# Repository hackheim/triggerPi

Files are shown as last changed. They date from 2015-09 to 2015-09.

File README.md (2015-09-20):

# triggerPi
DSLR Remote trigger kippah  for Raspberry Pi

<br />This work is licensed under a <a rel="license" href="http://creativecommons.org/licenses/by-sa/4.0/">Creative Commons Attribution-ShareAlike 4.0 International License</a>.

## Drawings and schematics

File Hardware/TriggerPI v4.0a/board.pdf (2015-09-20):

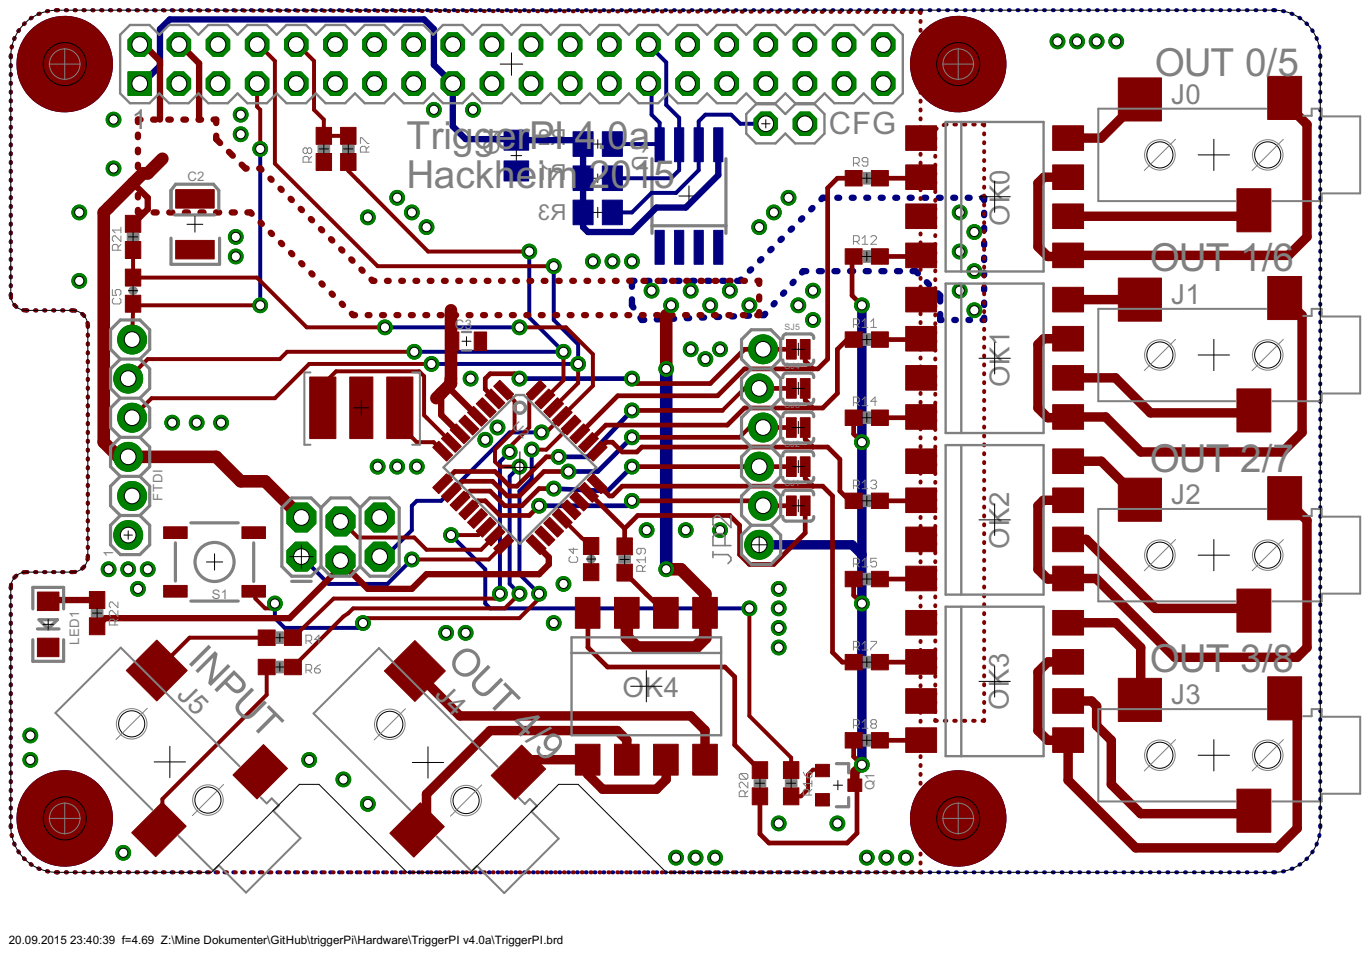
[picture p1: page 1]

20.09.2015 23:40:39 f=4.69 Z:\Mine Dokumenter\GitHub\triggerPi\Hardware\TriggerPI v4.0a\TriggerPI.brd

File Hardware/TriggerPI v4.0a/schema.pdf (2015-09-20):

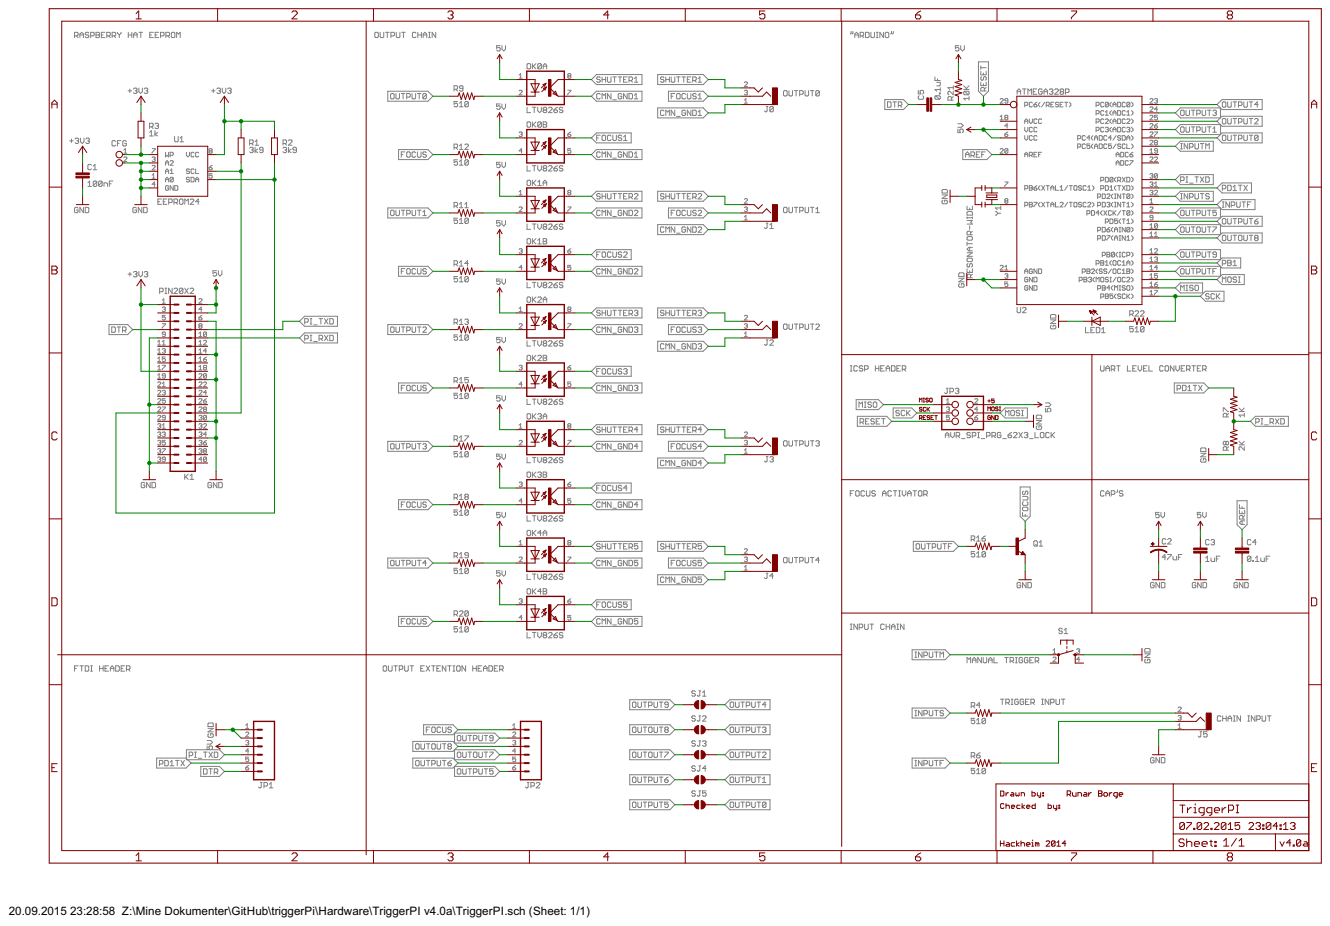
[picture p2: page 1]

20.09.2015 23:28:58 Z:\Mine Dokumenter\GitHub\triggerPi\Hardware\TriggerPI v4.0a\TriggerPI.sch (Sheet: 1/1)

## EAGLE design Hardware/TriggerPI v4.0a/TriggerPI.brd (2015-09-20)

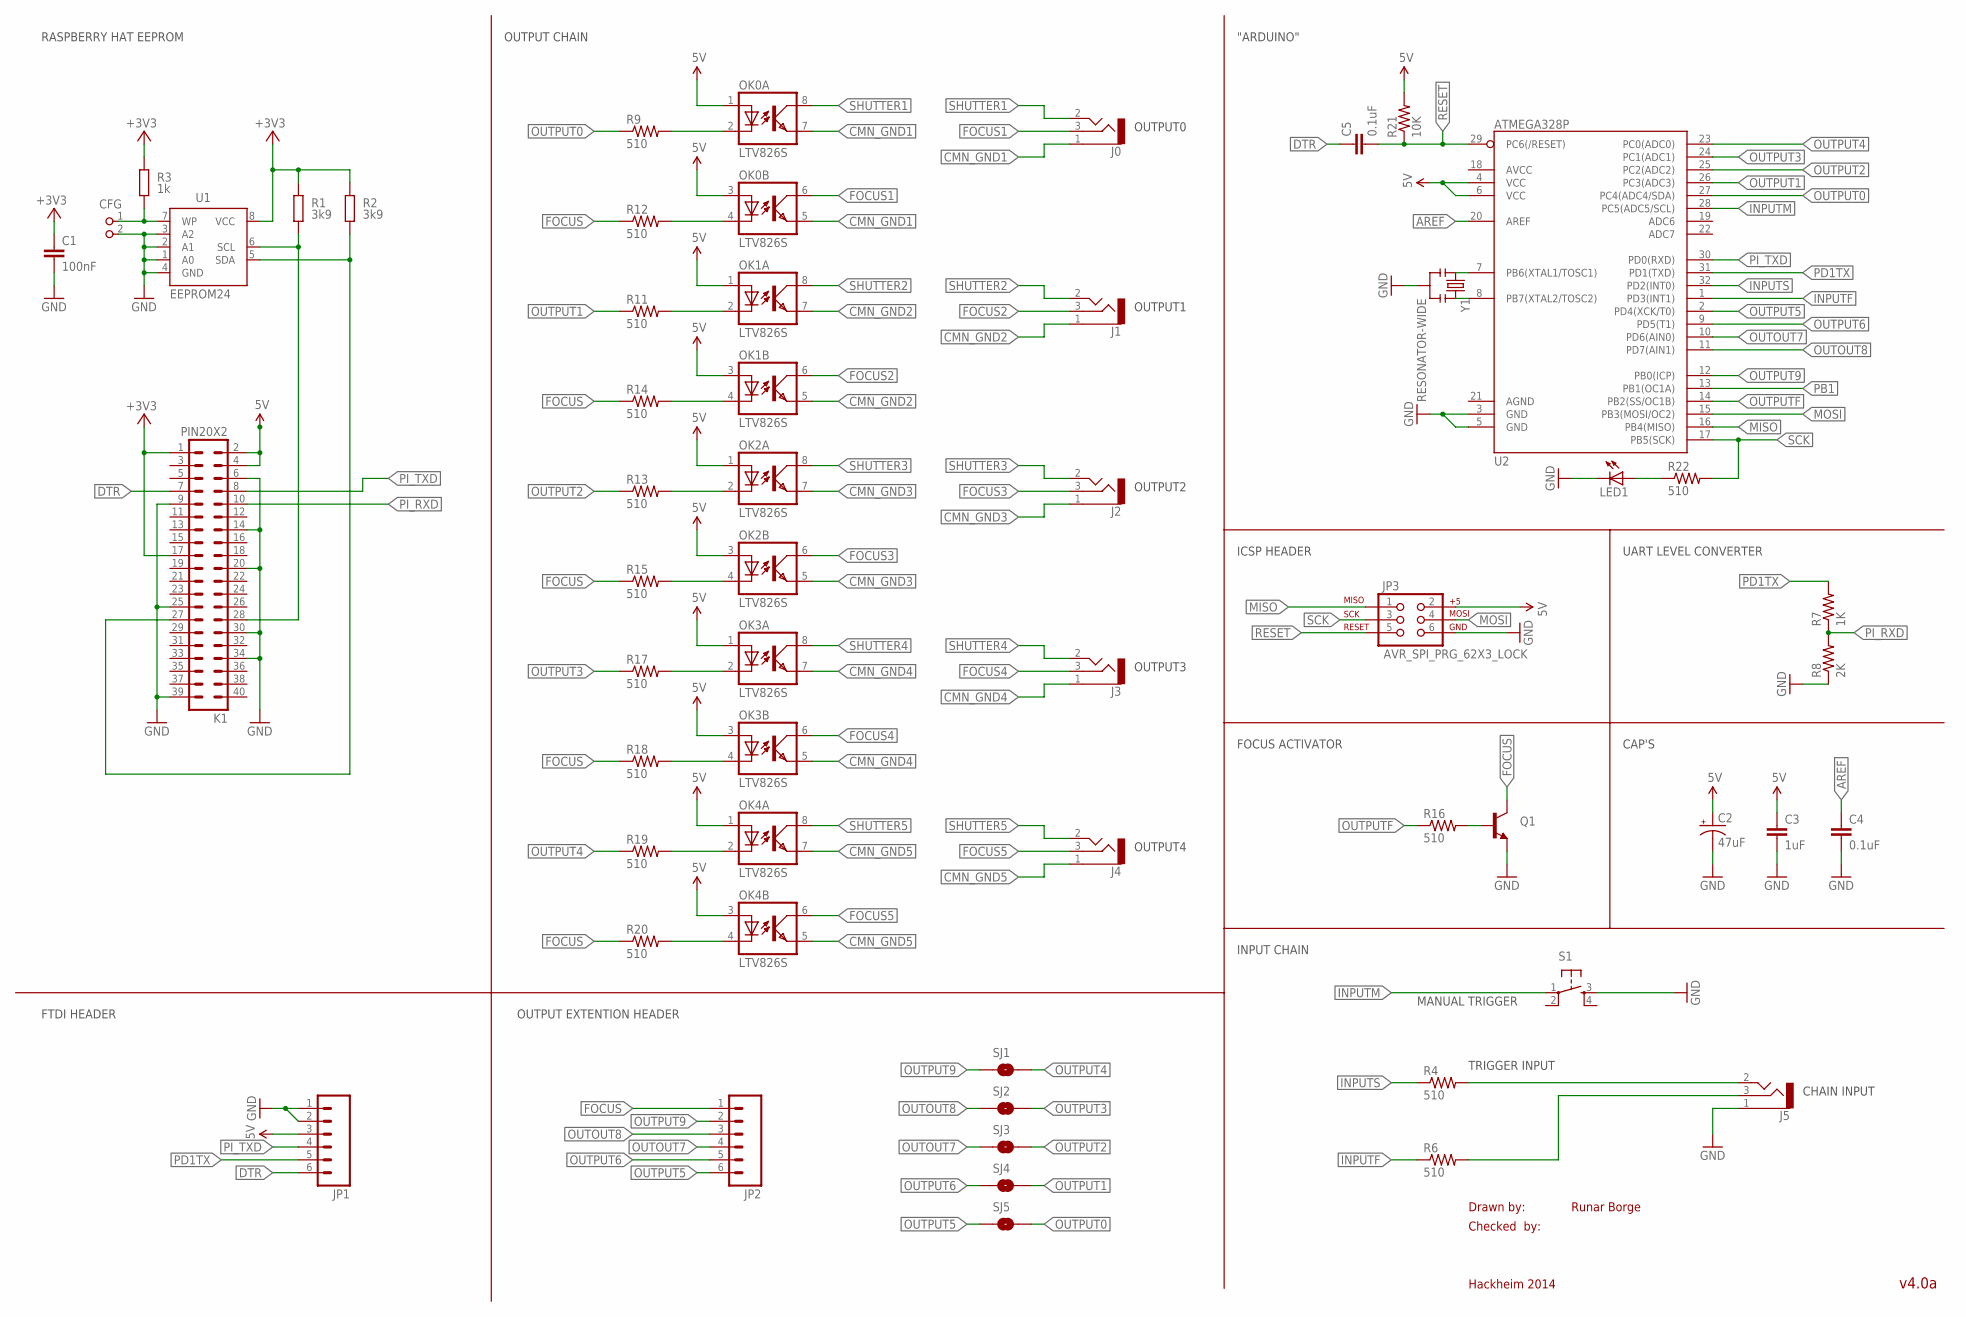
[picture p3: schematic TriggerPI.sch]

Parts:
C1: 100nF; C0805K
C2: 47uF; EIA3528; DIGIKEY 478-3132-1-ND
C3: 1uF; 0805; DIGIKEY 445-7547-1-ND
C4, C5: 0.1uF; 0603-CAP; DIGIKEY 445-1314-1-ND
CFG: PIN2_100; PIN_W_2
J0, J1, J2, J3, J4, J5: AUDIO-3P'SJ-3523-SMT'; 3P-SMD-3.5; DIGIKEY CP-3523SJCT-ND
JP1, JP2: M06LOCK; 1X06_LOCK
JP3: AVR_SPI_PRG_62X3_LOCK; 2X3_LOCK
K1: PIN20X2; PIN_20X2
LED1: LED1206; LED-1206; DIGIKEY 160-1405-1-ND
OK0, OK1, OK2, OK3, OK4: LTV826S; DIL8-SMD; DIGIKEY 160-1363-5-ND
Q1: TRANSISTOR_NPNSOT23-3; SOT23-3; DIGIKEY MMBT2222A-FDICT-ND
R1, R2: 3k9; M0805; TOLERANCE 5%
R3: 1k; M0805; TOLERANCE 5%
R4, R6, R9, R11, R12, R13, R14, R15, R16, R17, R18, R19, R20, R22: 510; 0603-RES; DIGIKEY RMCF0603JT510RCT-ND
R7: 1K; 0603-RES; DIGIKEY RMCF0603JT1K00CT-ND
R8: 2K; 0603-RES; DIGIKEY RMCF0603JT2K00CT-ND
R21: 10K; 0603-RES; DIGIKEY RMCF0603JT10K0CT-ND
S1: TAC_SWITCHSMD; TACTILE_SWITCH_SMD; DIGIKEY CKN9104CT-ND
SJ1, SJ2, SJ3, SJ4, SJ5: JUMPER-PAD-2-NOYES_SILK; PAD-JUMPER-2-NO_YES_SILK
U1: EEPROM24; SOIC8
U2: ATMEGA328P; TQFP32-08; DIGIKEY ATMEGA328P-AURCT-ND
Y1: RESONATOR-WIDE; RESONATOR-WIDE-SMD; DIGIKEY 1253-1084-1-ND

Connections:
5V: C2.A (+), C3.1, JP1.3, JP3.2, K1.2, K1.4, OK0.1 (A), OK0.3 (A), OK1.1 (A), OK1.3 (A), OK2.1 (A), OK2.3 (A), OK3.1 (A), OK3.3 (A), OK4.1 (A), OK4.3 (A), R21.2, U2.4 (VCC), U2.6 (VCC)
+3V3: C1.1, K1.1, K1.17, R1.2, R2.2, R3.2, U1.8 (VCC)
AREF: C4.1, U2.20 (AREF)
CMN_GND1: J0.1, OK0.5 (EMIT), OK0.7 (EMIT)
CMN_GND2: J1.1, OK1.5 (EMIT), OK1.7 (EMIT)
CMN_GND3: J2.1, OK2.5 (EMIT), OK2.7 (EMIT)
CMN_GND4: J3.1, OK3.5 (EMIT), OK3.7 (EMIT)
CMN_GND5: J4.1, OK4.5 (EMIT), OK4.7 (EMIT)
DTR: C5.1, JP1.6, K1.7
FOCUS: JP2.1, Q1.3 (C), R12.1, R14.1, R15.1, R18.1, R20.1
FOCUS0: J5.3 (2), R6.2
FOCUS1: J0.3 (2), OK0.6 (COL)
FOCUS2: J1.3 (2), OK1.6 (COL)
FOCUS3: J2.3 (2), OK2.6 (COL)
FOCUS4: J3.3 (2), OK3.6 (COL)
FOCUS5: J4.3 (2), OK4.6 (COL)
GND: C1.2, C2.C (-), C3.2, C4.2, CFG.2, J5.1, JP1.1, JP1.2, JP3.6, K1.6, K1.9, K1.14, K1.20, K1.25, K1.30, K1.34, K1.39, LED1.C, Q1.2 (E), R8.1, S1.3, U1.1 (A0), U1.2 (A1), U1.3 (A2), U1.4 (GND), U2.3 (GND), U2.5 (GND), Y1.2
INPUTF: R6.1, U2.1 (PD3(INT1))
INPUTM: S1.1, U2.28 (PC5(ADC5/SCL))
INPUTS: R4.1, U2.32 (PD2(INT0))
MISO: JP3.1, U2.16 (PB4(MISO))
MOSI: JP3.4, U2.15 (PB3(MOSI/OC2))
unnamed: K1.28, R1.1, U1.6 (SCL)
unnamed: K1.27, R2.1, U1.5 (SDA)
unnamed: CFG.1, R3.1, U1.7 (WP)
unnamed: J5.2 (5), R4.2
unnamed: OK0.2 (C), R9.2
unnamed: OK1.2 (C), R11.2
unnamed: OK2.2 (C), R13.2
unnamed: OK0.4 (C), R12.2
unnamed: Q1.1 (B), R16.2
unnamed: OK3.2 (C), R17.2
unnamed: OK3.4 (C), R18.2
unnamed: OK4.2 (C), R19.2
unnamed: OK4.4 (C), R20.2
unnamed: U2.7 (PB6(XTAL1/TOSC1)), Y1.1
unnamed: U2.8 (PB7(XTAL2/TOSC2)), Y1.3
unnamed: LED1.A, R22.1
unnamed: OK1.4 (C), R14.2
unnamed: OK2.4 (C), R15.2
OUTOUT7: JP2.4, SJ3.1, U2.10 (PD6(AIN0))
OUTOUT8: JP2.3, SJ2.1, U2.11 (PD7(AIN1))
OUTPUT0: R9.1, SJ5.2, U2.27 (PC4(ADC4/SDA))
OUTPUT1: R11.1, SJ4.2, U2.26 (PC3(ADC3))
OUTPUT2: R13.1, SJ3.2, U2.25 (PC2(ADC2))
OUTPUT3: R17.1, SJ2.2, U2.24 (PC1(ADC1))
OUTPUT4: R19.1, SJ1.2, U2.23 (PC0(ADC0))
OUTPUT5: JP2.6, SJ5.1, U2.2 (PD4(XCK/T0))
OUTPUT6: JP2.5, SJ4.1, U2.9 (PD5(T1))
OUTPUT9: JP2.2, SJ1.1, U2.12 (PB0(ICP))
OUTPUTF: R16.1, U2.14 (PB2(SS/OC1B))
PB1: U2.13 (PB1(OC1A))
PD1TX: JP1.5, R7.2, U2.31 (PD1(TXD))
PI_RXD: K1.10, R7.1, R8.2
PI_TXD: JP1.4, K1.8, U2.30 (PD0(RXD))
RESET: C5.2, JP3.5, R21.1, U2.29 (PC6(/RESET))
SCK: JP3.3, R22.2, U2.17 (PB5(SCK))
SHUTTER1: J0.2 (5), OK0.8 (COL)
SHUTTER2: J1.2 (5), OK1.8 (COL)
SHUTTER3: J2.2 (5), OK2.8 (COL)
SHUTTER4: J3.2 (5), OK3.8 (COL)
SHUTTER5: J4.2 (5), OK4.8 (COL)

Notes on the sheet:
Drawn by:
Checked by:
Hackheim 2014
Runar Borge
v4.0a
CHAIN INPUT
OUTPUT0
OUTPUT1
OUTPUT2
OUTPUT3
OUTPUT4
MANUAL TRIGGER
INPUT CHAIN
OUTPUT CHAIN
ICSP HEADER
FTDI HEADER
FOCUS ACTIVATOR
UART LEVEL CONVERTER
"ARDUINO"
TRIGGER INPUT
CAP'S
RASPBERRY HAT EEPROM
OUTPUT EXTENTION HEADER

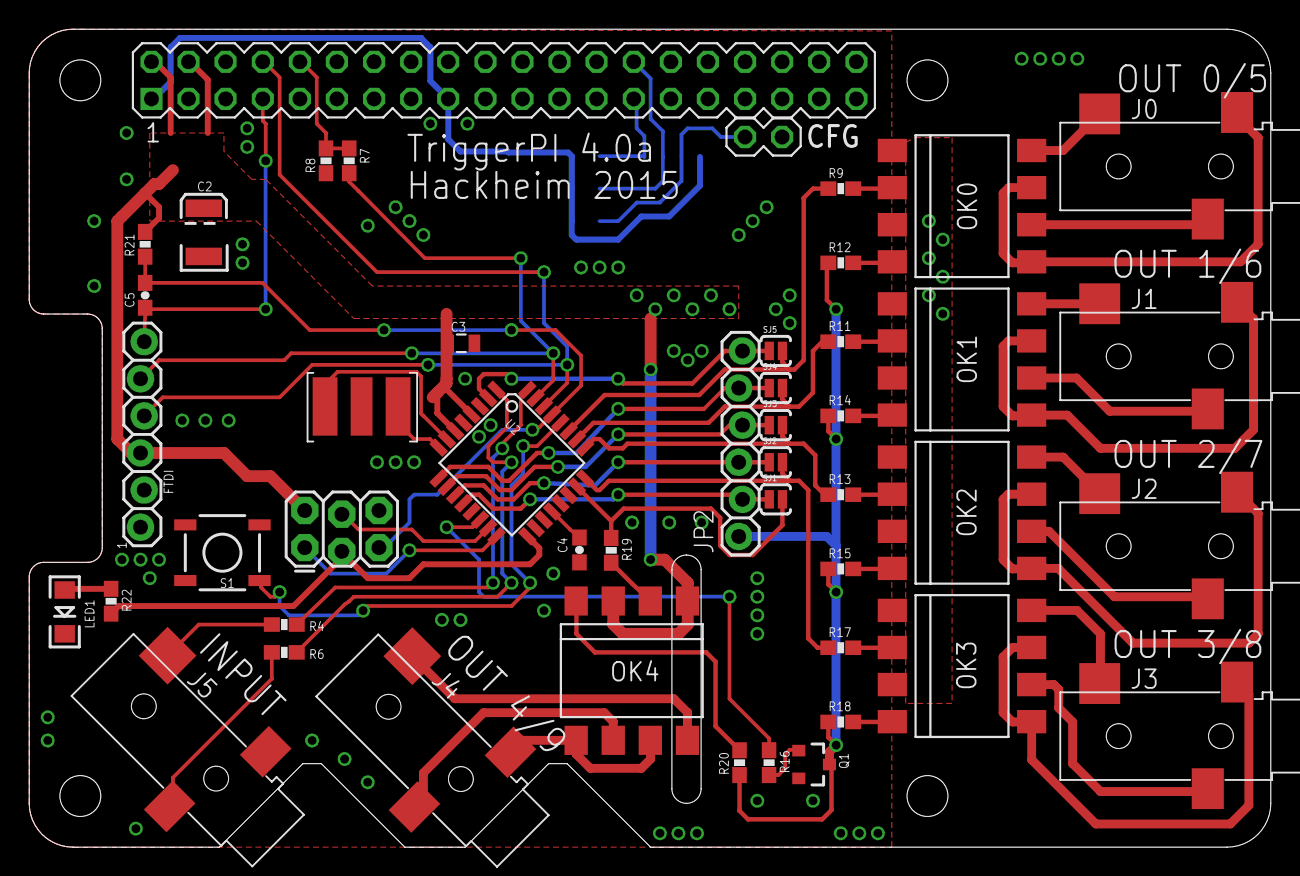
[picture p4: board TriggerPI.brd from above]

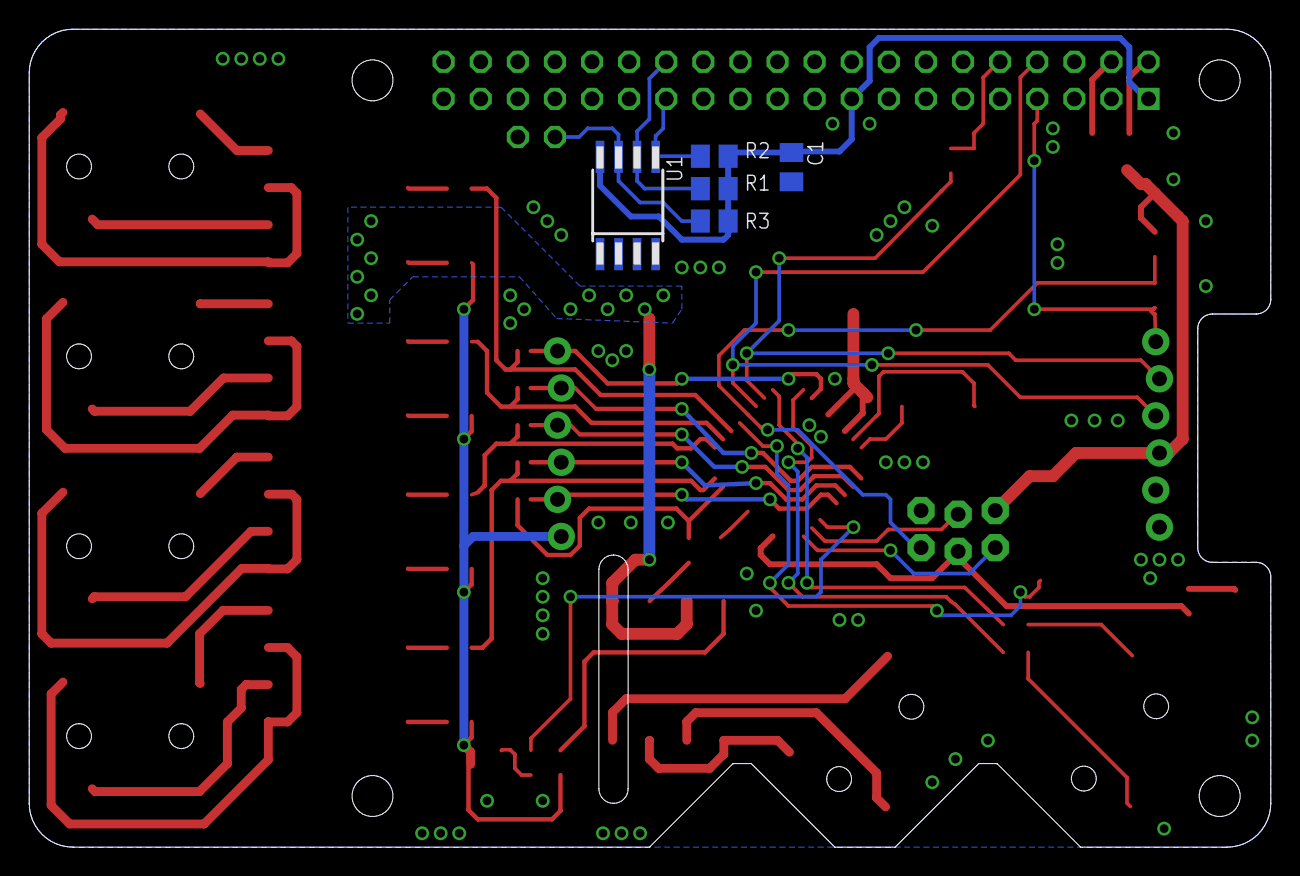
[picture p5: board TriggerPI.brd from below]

Board: 2 copper layers, 85.0 x 56.0 mm, 52 parts (5 on the bottom side), 61 nets.

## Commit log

2015-09-20 Uploaded version 4.0a
    [TriggerPI.brd, TriggerPI.sch]
2015-09-20 Uploaded board in pdf format

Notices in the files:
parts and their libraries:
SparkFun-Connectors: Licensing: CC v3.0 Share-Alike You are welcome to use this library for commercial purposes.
